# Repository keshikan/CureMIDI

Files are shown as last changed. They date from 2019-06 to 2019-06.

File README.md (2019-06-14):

# USB-MIDI Interface (2IN/2OUT) for STM32 "CureMIDI"

## Overview

This repository shows STM32F0 (ARM Cortex-M0) based USB-MIDI Interface.
It has 2 MIDI-IN and 2 MIDI-OUT, and is USB MIDI class-compliant.

The USB-MIDI Class Driver is based on [mimuz-tuch](https://github.com/mimuz/mimuz-tuch) project (c) [D.F.Mac. @TripArts Music](https://github.com/tadfmac).

STM32F0を使用した、USB-MIDIインターフェースです。INを2系統、OUTを2系統実装しています。USB MIDI Classに対応するシステム(Windows, iOS, Android, etc.)に対し、ドライバレスでMIDI入出力ポートを追加できます。

USB MIDI Classドライバは、[D.F.Mac. @TripArts Music](https://github.com/tadfmac)氏作成の[ドライバ](https://github.com/mimuz/mimuz-tuch/tree/master/STM32)を基に、一部改造を加えています。

Sample Image

## Specifications

* USB MIDI class-compliant
* MIDI port: 2IN/2OUT
* MIDI buffer size: 512B/1port

## Building Information

### Making hardware

See [Schematic](./hardware/schematic.pdf), [KiCad Source](./hardware/kicad_source).

### Building software

Install [SW4STM32](http://www.openstm32.org/HomePage)(need registration), import [Project files](./software/SW4STM32_project/), and build.

## File Location

* [Binary file for STM32F042](./software/bin/)
* [STM32CubeMX Project file](./software/SW4STM32_project/CureMIDI_IF.ioc)
* [Source codes and project files (System WorkBench for STM32)](./software/SW4STM32_project/)
* [Schematic](./hardware/schematic.pdf)

## NOTICE

### VID/PID

Vendor ID(VID) and Product ID(PID) in <usbd_desc.c> should be unique pair for each USB devices.
Default VID 0x1209 and PID 0x0001 is experimental IDs from [http://pid.codes](http://pid.codes) .When distributing or selling, you must get your own IDs, and change to your own IDs in order to avoid conflicting to other USB devices.

USBのVendor ID(VID)とProduct ID(PID)は、<usbd_desc.c>内に記述します。
デフォルトのVID(0x1209)/PID(0x0001)ペアは、[http://pid.codes](http://pid.codes)で定められている実験用IDです。そのため、本機器を配布したり販売したりする場合には、別途固有のIDペアを取得し、書き換えてご使用下さい。

## References

### MIDI specification

* [The Complete MIDI 1.0 Detailed Specification](https://www.midi.org/specifications/item/the-midi-1-0-specification) ([MIDI Association](https://www.midi.org/))
* [MIDI1.0規格書](http://amei.or.jp/midistandardcommittee/MIDI1.0.pdf) ([AMEI](http://amei.or.jp/))
* [MIDIの学習](http://www1.plala.or.jp/yuuto/midi/index.html) ([Laboratory "U"](http://www1.plala.or.jp/yuuto/top.html))

### USB-MIDI technical information

* [Universal Serial Bus Device Class Definition for MIDI Devices](http://www.usb.org/developers/docs/devclass_docs/midi10.pdf)
* [USBおよびUSB MIDIについて調べる](http://picmidi.seesaa.net/article/150728556.html) ([PICでMIDI！](http://picmidi.seesaa.net/))

## Copyrights

* USB MIDI Class Driver by [D.F.Mac. @TripArts Music](http://ta-music.strikingly.com/)
* STM32 CubeF0 by [STMicroelectronics](https://www.st.com/en/embedded-software/stm32cubef0.html)

## Author

(c) 2018 Keshikan ( [Website](http://www.keshikan.net/),  [Twitter](https://twitter.com/keshinomi_88pro) )

## License

* USB MIDI Class Driver: [CC BY 4.0](https://creativecommons.org/licenses/by/4.0/)
* STM32 CubeF0: BSD-3-Clause based.
* Other Codes, Hardware, Schematic: [GPLv3](https://www.gnu.org/licenses/gpl-3.0.html)

See also [LICENSE.md](./LICENSE.md)

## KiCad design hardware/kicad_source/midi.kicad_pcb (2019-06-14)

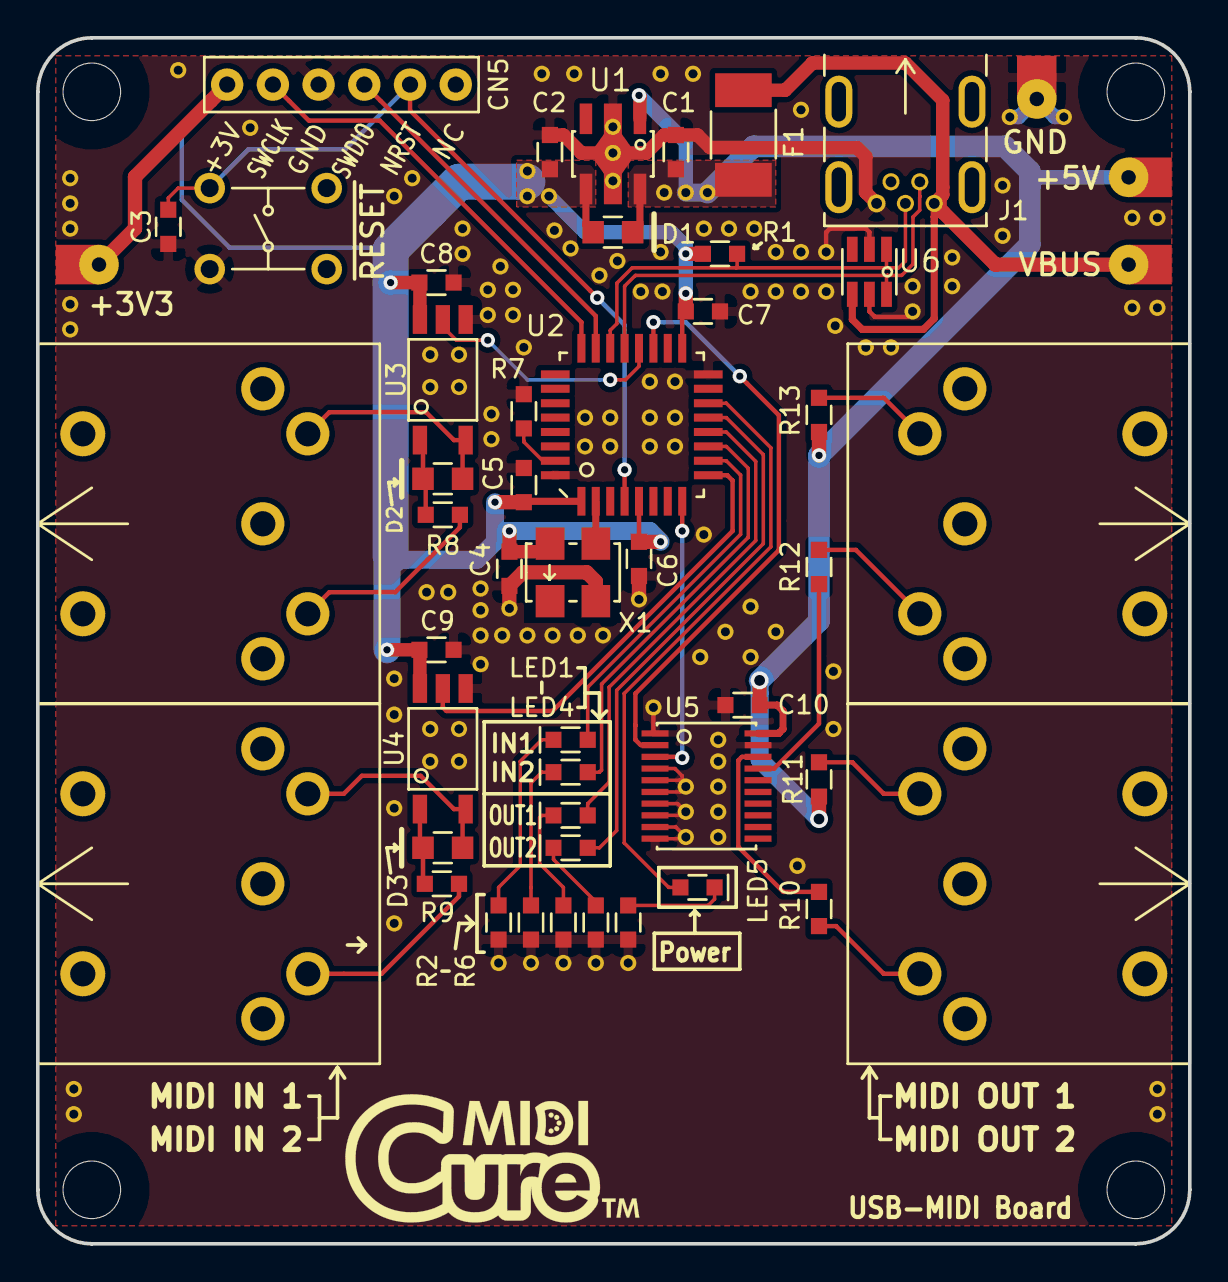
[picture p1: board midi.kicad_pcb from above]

Board: 2 copper layers, 64.0 x 67.0 mm, 50 parts (0 on the bottom side), 37 nets.

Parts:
C1: 0.33μF; SMD_0603(1608)
C2: 2.2μF; SMD_0603(1608)
C3, C4, C5, C6, C7, C8, C9, C10: 0.1μF; SMD_0603(1608)
CN1, CN2, CN3, CN4: DIN_5; DIN_5P_MIDI
CN5: CONN_01X06; CONN_DIP_6Pin
D1: D_Schottky_Small; SMD_0805(2012)_polar
D2, D3: D_Small; SMD_0805(2012)_polar
F1: PolySW 0.35A; miniSMDC030F
J1: USB_OTG_ORIG; USB_miniB_MUSB-5BF01AS
LED1, LED2, LED3, LED4, LED5: Led_Small; SMD_0603(1608)_polar
P1: VBUS; CHK_Terminal_TH
P2: 5V; CHK_Terminal_TH
P3: CHK_GND; CHK_Terminal_TH
P4: 3V; CHK_Terminal_TH
R1: 4.7k; SMD_0603(1608)
R2, R3, R4, R5, R6: 750; SMD_0603(1608)
R7: 10k; SMD_0603(1608)
R8, R9, R10, R11, R12, R13: 220; SMD_0603(1608)
SW1: SW_PUSH_SMALL_H; Tactile_Switches_2by2
U1: NJM2884U1; SOT-89-5
U2: STM32F042K6Tx; LQFP32_7x7_STM32
U3, U4: TLP2361; 11-4L1S(TLP2361)
U5: 74VHCV541FT; TSSOP20B
U6: ESDA6V1BC6; SOT23-6L
X1: SG5032CAN 8MHz; SG5032

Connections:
+3V3: C2.1, C4.1, C5.1, C6.1, C7.1, C8.1, C9.1, CN5.1, D1.2, P4.1, R1.2, U1.VO, U2.1, U2.5, U2.17, U3.6, U4.6, X1.4
+5V: C1.1, C10.1, D1.1, F1.1, P2.1, R11.1, R13.1, U1.CTR, U1.VI, U5.20
GNDD: C1.2, C2.2, C3.2, C4.2, C5.2, C6.2, C7.2, C8.2, C9.2, C10.2, CN5.3, J1.5, P3.1, R2.1, R3.1, R4.1, R5.1, R6.1, R7.1, SW1.1, U1.GND, U2.16, U2.32, U3.4, U4.4, U5.1, U5.4, U5.5, U5.6, U5.7, U5.8, U5.9, U5.10, U5.19, U6.2, U6.5, X1.2
MIDI_IN_1: U2.20, U3.5
MIDI_IN_2: U2.9, U4.5
MIDI_OUT_1: U2.19, U5.2
MIDI_OUT_2: U2.8, U5.3
NRST: C3.1, CN5.5, SW1.2, U2.4
unnamed: CN1.4, R8.1
unnamed: CN1.5, D2.2, U3.3
unnamed: CN2.4, R9.1
unnamed: CN2.5, D3.2, U4.3
unnamed: CN3.4, R11.2
unnamed: CN3.5, R10.2
unnamed: CN4.4, R13.2
unnamed: CN4.5, R12.2
unnamed: D2.1, R8.2, U3.1
unnamed: D3.1, R9.2, U4.1
unnamed: LED1.1, R2.2
unnamed: LED1.2, U2.10
unnamed: LED2.1, R3.2
unnamed: LED2.2, U2.11
unnamed: LED3.1, R4.2
unnamed: LED3.2, U2.12
unnamed: LED4.1, R5.2
unnamed: LED4.2, U2.13
unnamed: LED5.1, R6.2
unnamed: LED5.2, U2.14
unnamed: R7.2, U2.31
unnamed: R10.1, U5.18
unnamed: R12.1, U5.17
unnamed: U2.2, X1.3
SWCLK: CN5.2, U2.24
SWDIO: CN5.4, U2.23
USBD_N: J1.2, U2.21, U6.6
USBD_P: J1.3, R1.1, U2.22, U6.1
VBUS: F1.2, J1.1, P1.1, U6.4
